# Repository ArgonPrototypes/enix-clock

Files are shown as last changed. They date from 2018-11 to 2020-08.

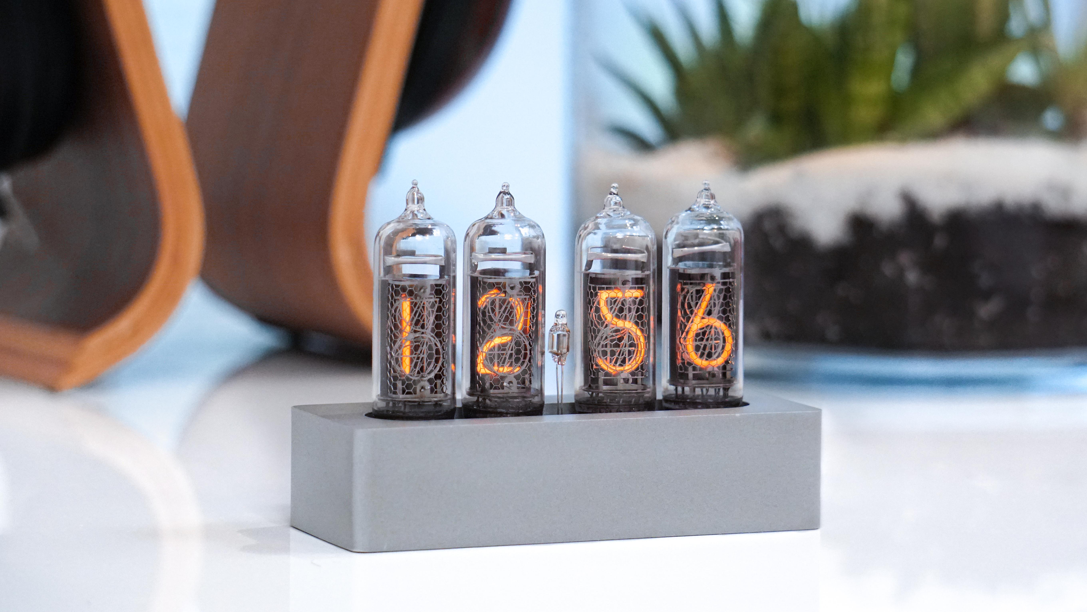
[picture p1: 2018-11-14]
MEDIA/Photos of the Enix/Kickstarter Promo Photo.jpg

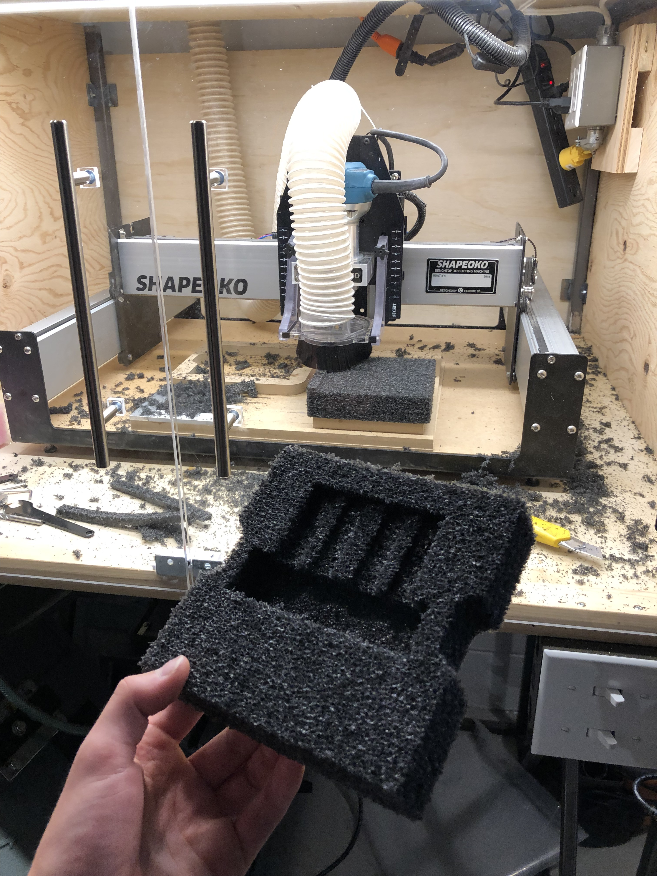
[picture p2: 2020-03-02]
PACKAGING/Top Foam/CNC Milled Foam.jpeg

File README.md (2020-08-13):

# Enix: The Modern Nixie Clock
### A beautifully sleek product that gives new life to vintage components
#### Learn more at our website: https://www.argonprototypes.com/
This repository contains hardware, software, CAD files, and much more!



# More info about each section:
## Electronic Hardware:
The circuit board was designed in EAGLE CAD V9.2.2. Most dimensions are in mm on this board. The Gerber files are in RS-274X and Excellon drill format. There are several external libraries used; Sparkfun, Adafruit, MacroFab, and a couple more for unique parts. There should not be any problems with opening the design files without the libraries installed.

Bottom Board
Top Board
## Software:
The majority of the software is written in VS Code with the PlatformIO extension, however the Arduino IDE works just as well. The microcontroller used is the ATMega32u4, which has an 8 bit architecture with a 16MHz clock speed, is 5V tolerant, and includes built in USB programmability. This microcontroller is found on the Arduino Micro, which can be selected from the IDE to be able to upload to the board.<br/> The libraries used are Arduino.h, TimerOne.h, RTClib.h, Adafruit_NeoPixel.h, Adafruit MCP9808.h, Wire.h, and EEPROM.h.

## Case
The outer case is a CNC milled block of Aluminum or Wood. The Aluminum cases are Vapour Blasted to give a satin look, and then Anodized in Black or Clear to add a protective coating. The Wood cases are sanded to a smooth finish, prior to coating in polyurethane or oil. <br/> To hold the electronics in the case, there is a 3D printed bottom plate which uses heat set inserts to bolt to the circuit board.

## Packaging
To safely ship the Enix, a custom cardboard box with the internal dimensions of 6x6x3" was designed and ordered through Packlane. 2 Foam CNC milled inserts tightly pack the clock and all included accessories, which includes the Enix, some stickers, a drink coaster, instruction manual, and a Mini-USB cable.<br/>
The Packlane box is shipped in a larger 8x8x5" standard cardboard box filled with packing peanuts to give added protection in shipping.

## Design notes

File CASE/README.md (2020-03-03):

# Files for the Case and Bottom Plate
##Case
##Bottom Plate
The bottom plate uses 4 M3 x 5mm Length x 3mm Outer Diameter brass heat set inserts and 4 button head Philips M3 x 6mm long bolts to fasten the bottom circuit board.<br/> The rectangular cutout on the bottom is to access the removable CR2032 battery which maintains timekeeping while the clock is unplugged. The case is connected to plate using 2 M3 countersunk Philips bolts made by Hammond Manufacturing - part number 1599HMS100BK for black and 1599HMS100 for silver.

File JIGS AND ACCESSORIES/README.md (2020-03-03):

# Jigs and Accessories
## Includes:
* 3D printed parts for bootloading the boards
* Pin header caps to prevent shorting the case and top PCB pins
* CNC fixtures for milling the foam packaging
* Nixie tube jig for evenly soldering in each tube

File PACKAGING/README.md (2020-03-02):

# Enix Clock Packaging
### The box the Enix ships in has an internal dimension of 6x6x3". To hold the clock and accessories, 1.5" laminated black polyethylene is CNC milled.
#CNC Milling Information
The foam inserts were machined using a Shapeoko 3 with a 6mm end mill made by Datron. The Datron product code is 00680560. A straight cut 6mm 2-flute from eBay was initially tested but with significantly worse results!
The Shapeoko's acceleration and maximum feedrates were increased through the MDI to speed up the cycle time as well.

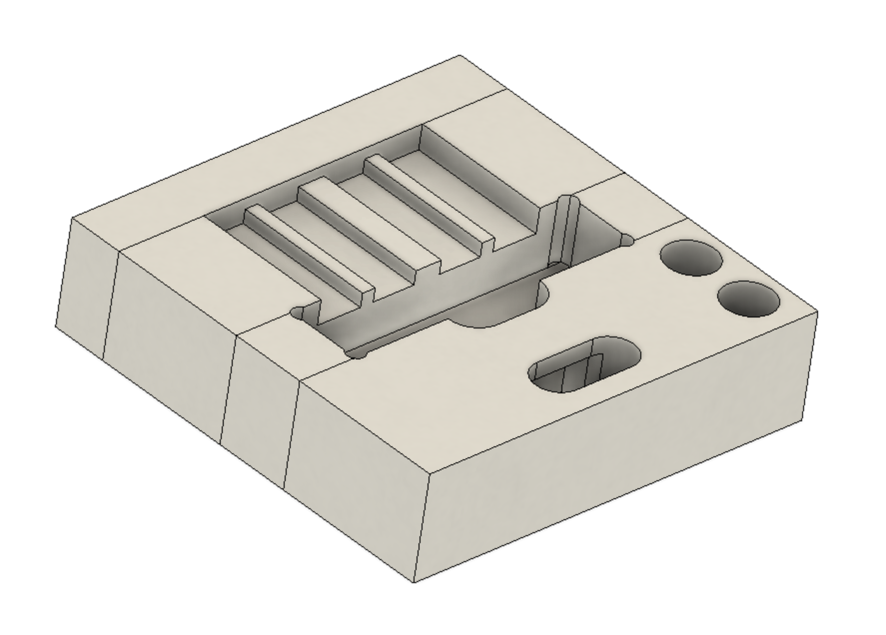
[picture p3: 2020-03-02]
PACKAGING/Bottom Foam/Rendered Photo Packaging Clock Side.png

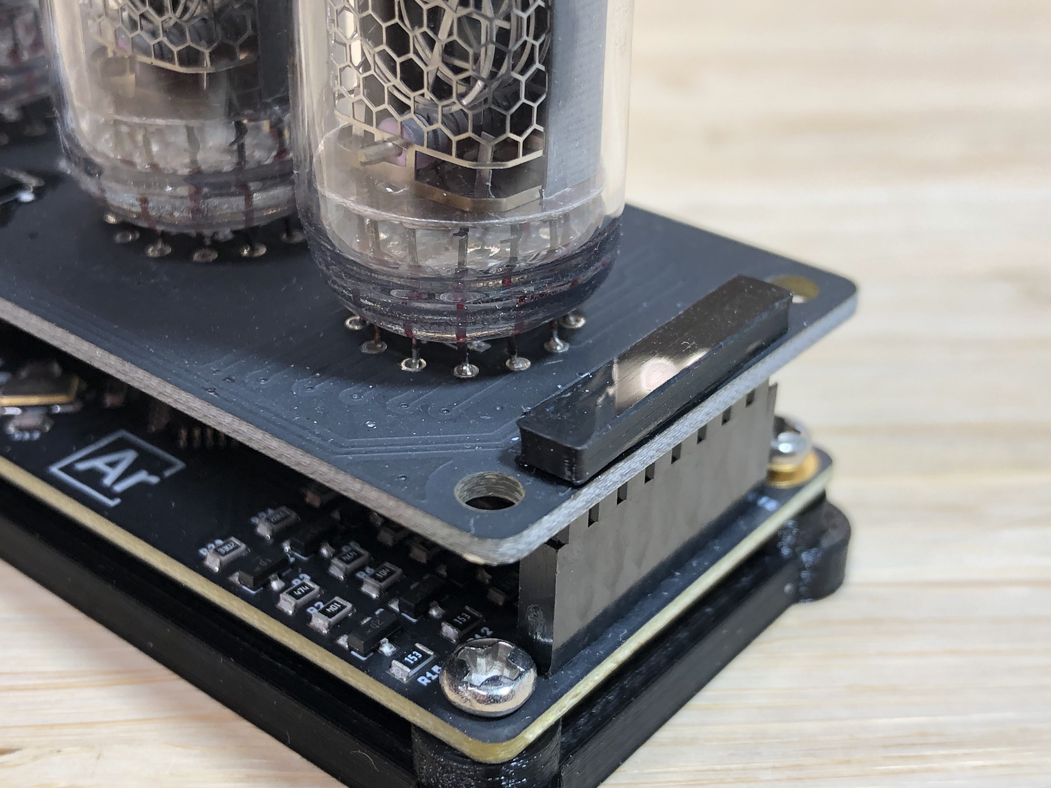
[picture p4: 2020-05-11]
JIGS AND ACCESSORIES/Pin Header Caps/1x8 Epoxied to Clock.jpeg

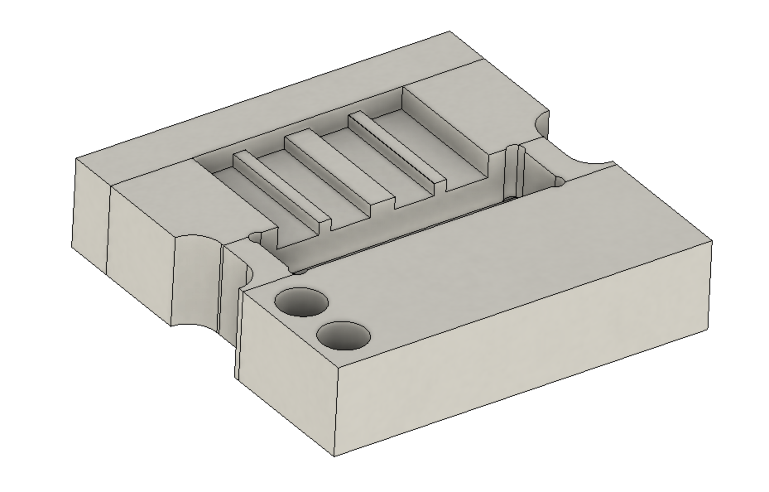
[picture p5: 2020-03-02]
PACKAGING/Top Foam/Rendered Packaging.png

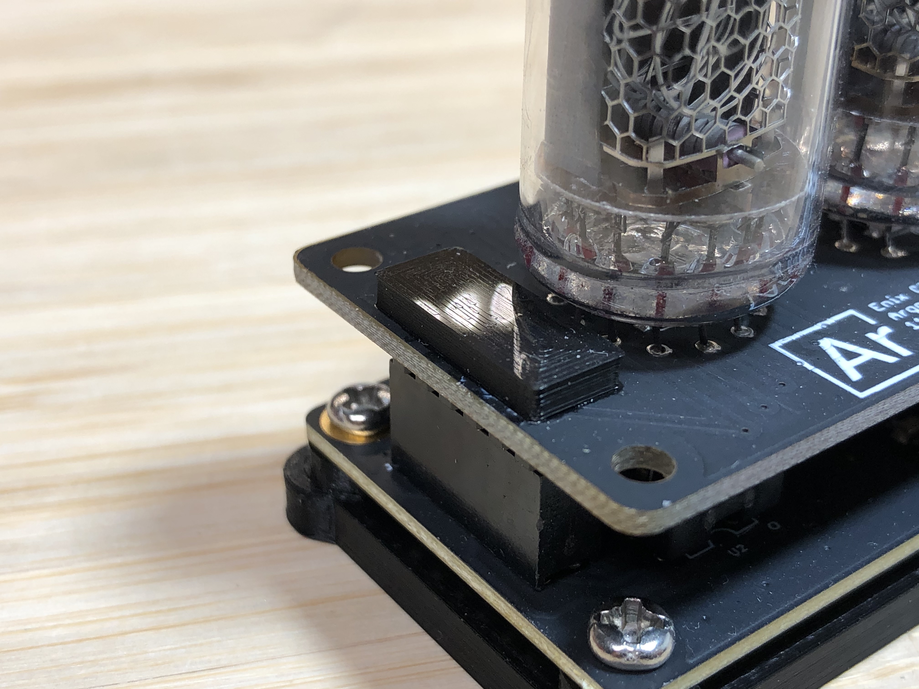
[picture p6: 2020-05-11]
JIGS AND ACCESSORIES/Pin Header Caps/2x6 Epoxied to Clock.jpeg

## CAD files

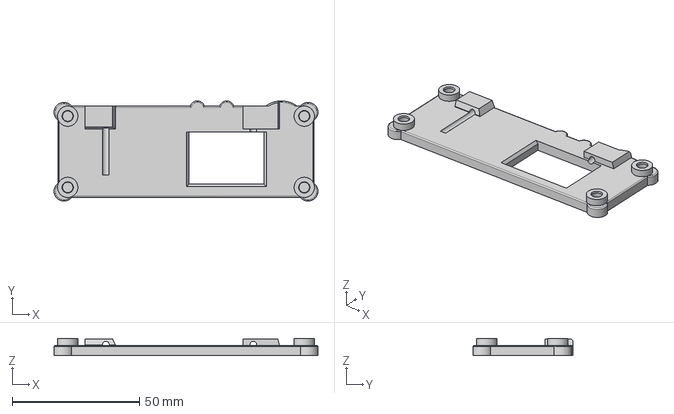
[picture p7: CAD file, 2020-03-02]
CASE/Bottom Plate - 3D printed/BottomPlate.step
103.8 x 39.4 x 6.75 mm

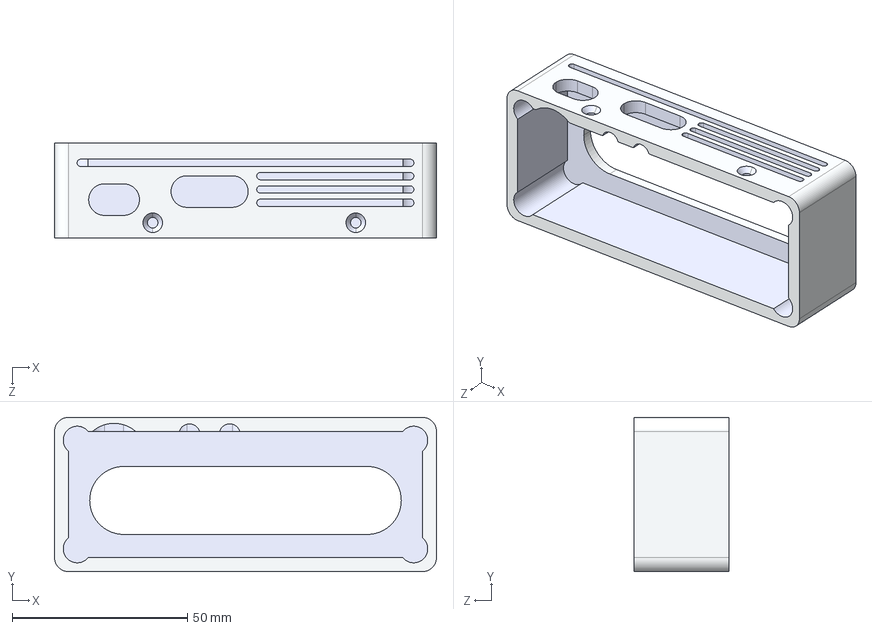
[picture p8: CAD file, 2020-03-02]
CASE/Top Case - CNC Milled/EnixCase.STEP
109.0 x 44.0 x 27.0 mm

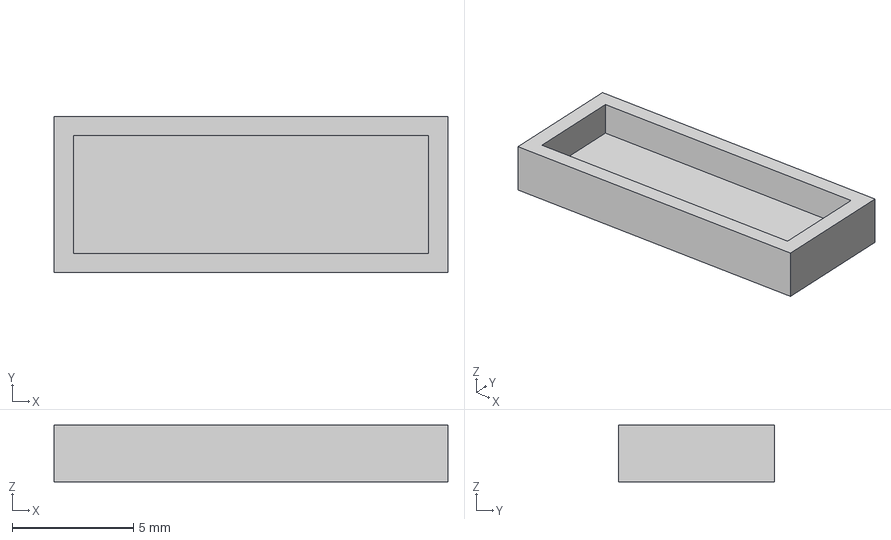
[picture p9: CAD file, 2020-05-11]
JIGS AND ACCESSORIES/Pin Header Caps/PinheaderCap2x6.step
16.2 x 6.45 x 2.35 mm

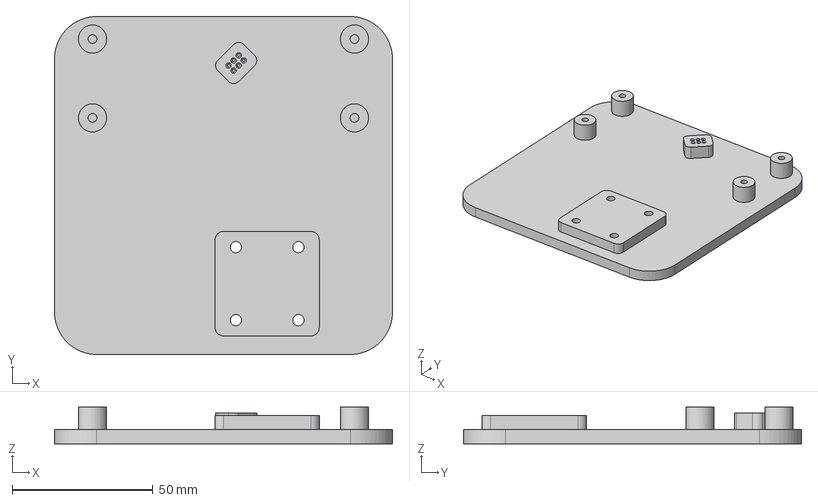
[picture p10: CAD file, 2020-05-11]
JIGS AND ACCESSORIES/Programming Jig/ProgrammingJig.step
120.0 x 120.0 x 13.0 mm

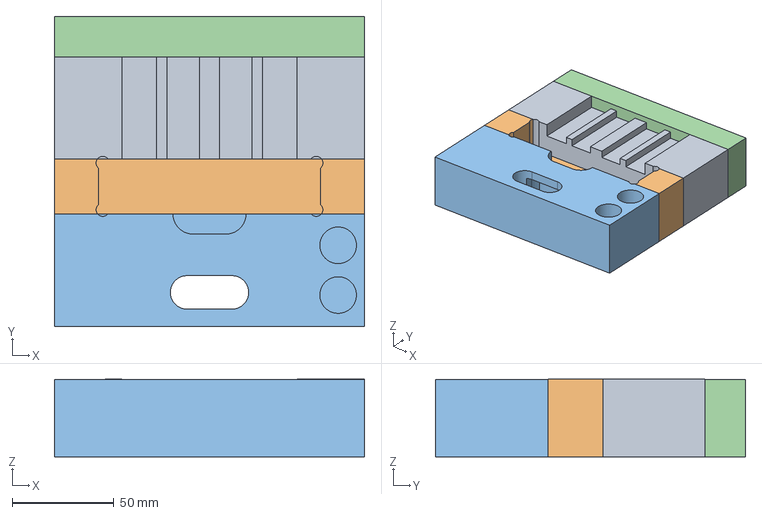
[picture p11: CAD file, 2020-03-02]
PACKAGING/Bottom Foam/Bottom Half Foam Packaging.step
152.5 x 152.4 x 38.1 mm

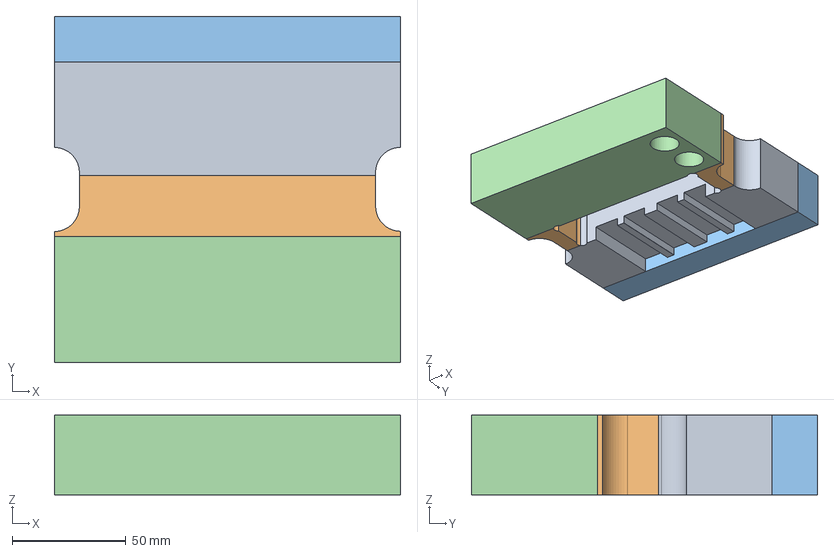
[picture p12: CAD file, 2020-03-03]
PACKAGING/Top Foam/Top Half Foam Packaging.step
152.5 x 152.4 x 35.1 mm

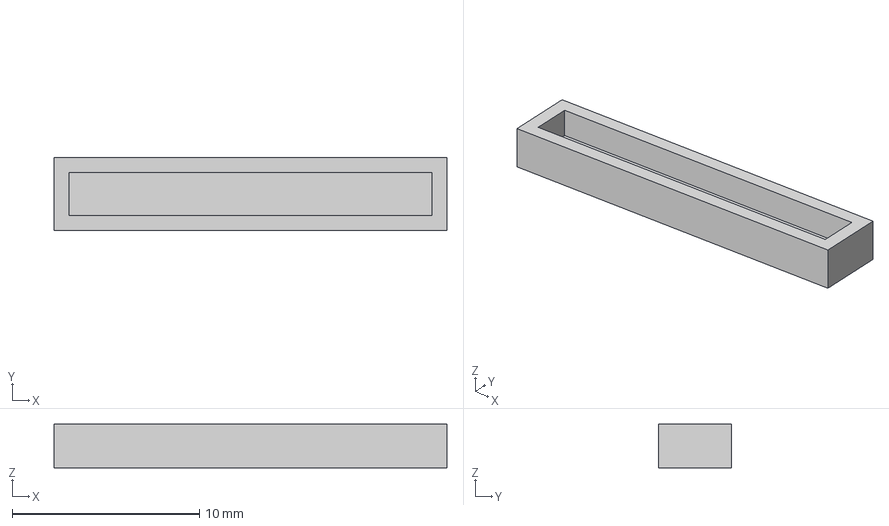
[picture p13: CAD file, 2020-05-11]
JIGS AND ACCESSORIES/Pin Header Caps/PinheaderCap1x8.step
21.0 x 3.90 x 2.35 mm

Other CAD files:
CASE/Bottom Plate - 3D printed/BottomPlate.stl
CASE/Top Case - CNC Milled/EnixCase.stl
JIGS AND ACCESSORIES/Pin Header Caps/PinheaderCap1x8.stl
JIGS AND ACCESSORIES/Pin Header Caps/PinheaderCap2x6.stl
JIGS AND ACCESSORIES/Programming Jig/ProgrammingJig.stl

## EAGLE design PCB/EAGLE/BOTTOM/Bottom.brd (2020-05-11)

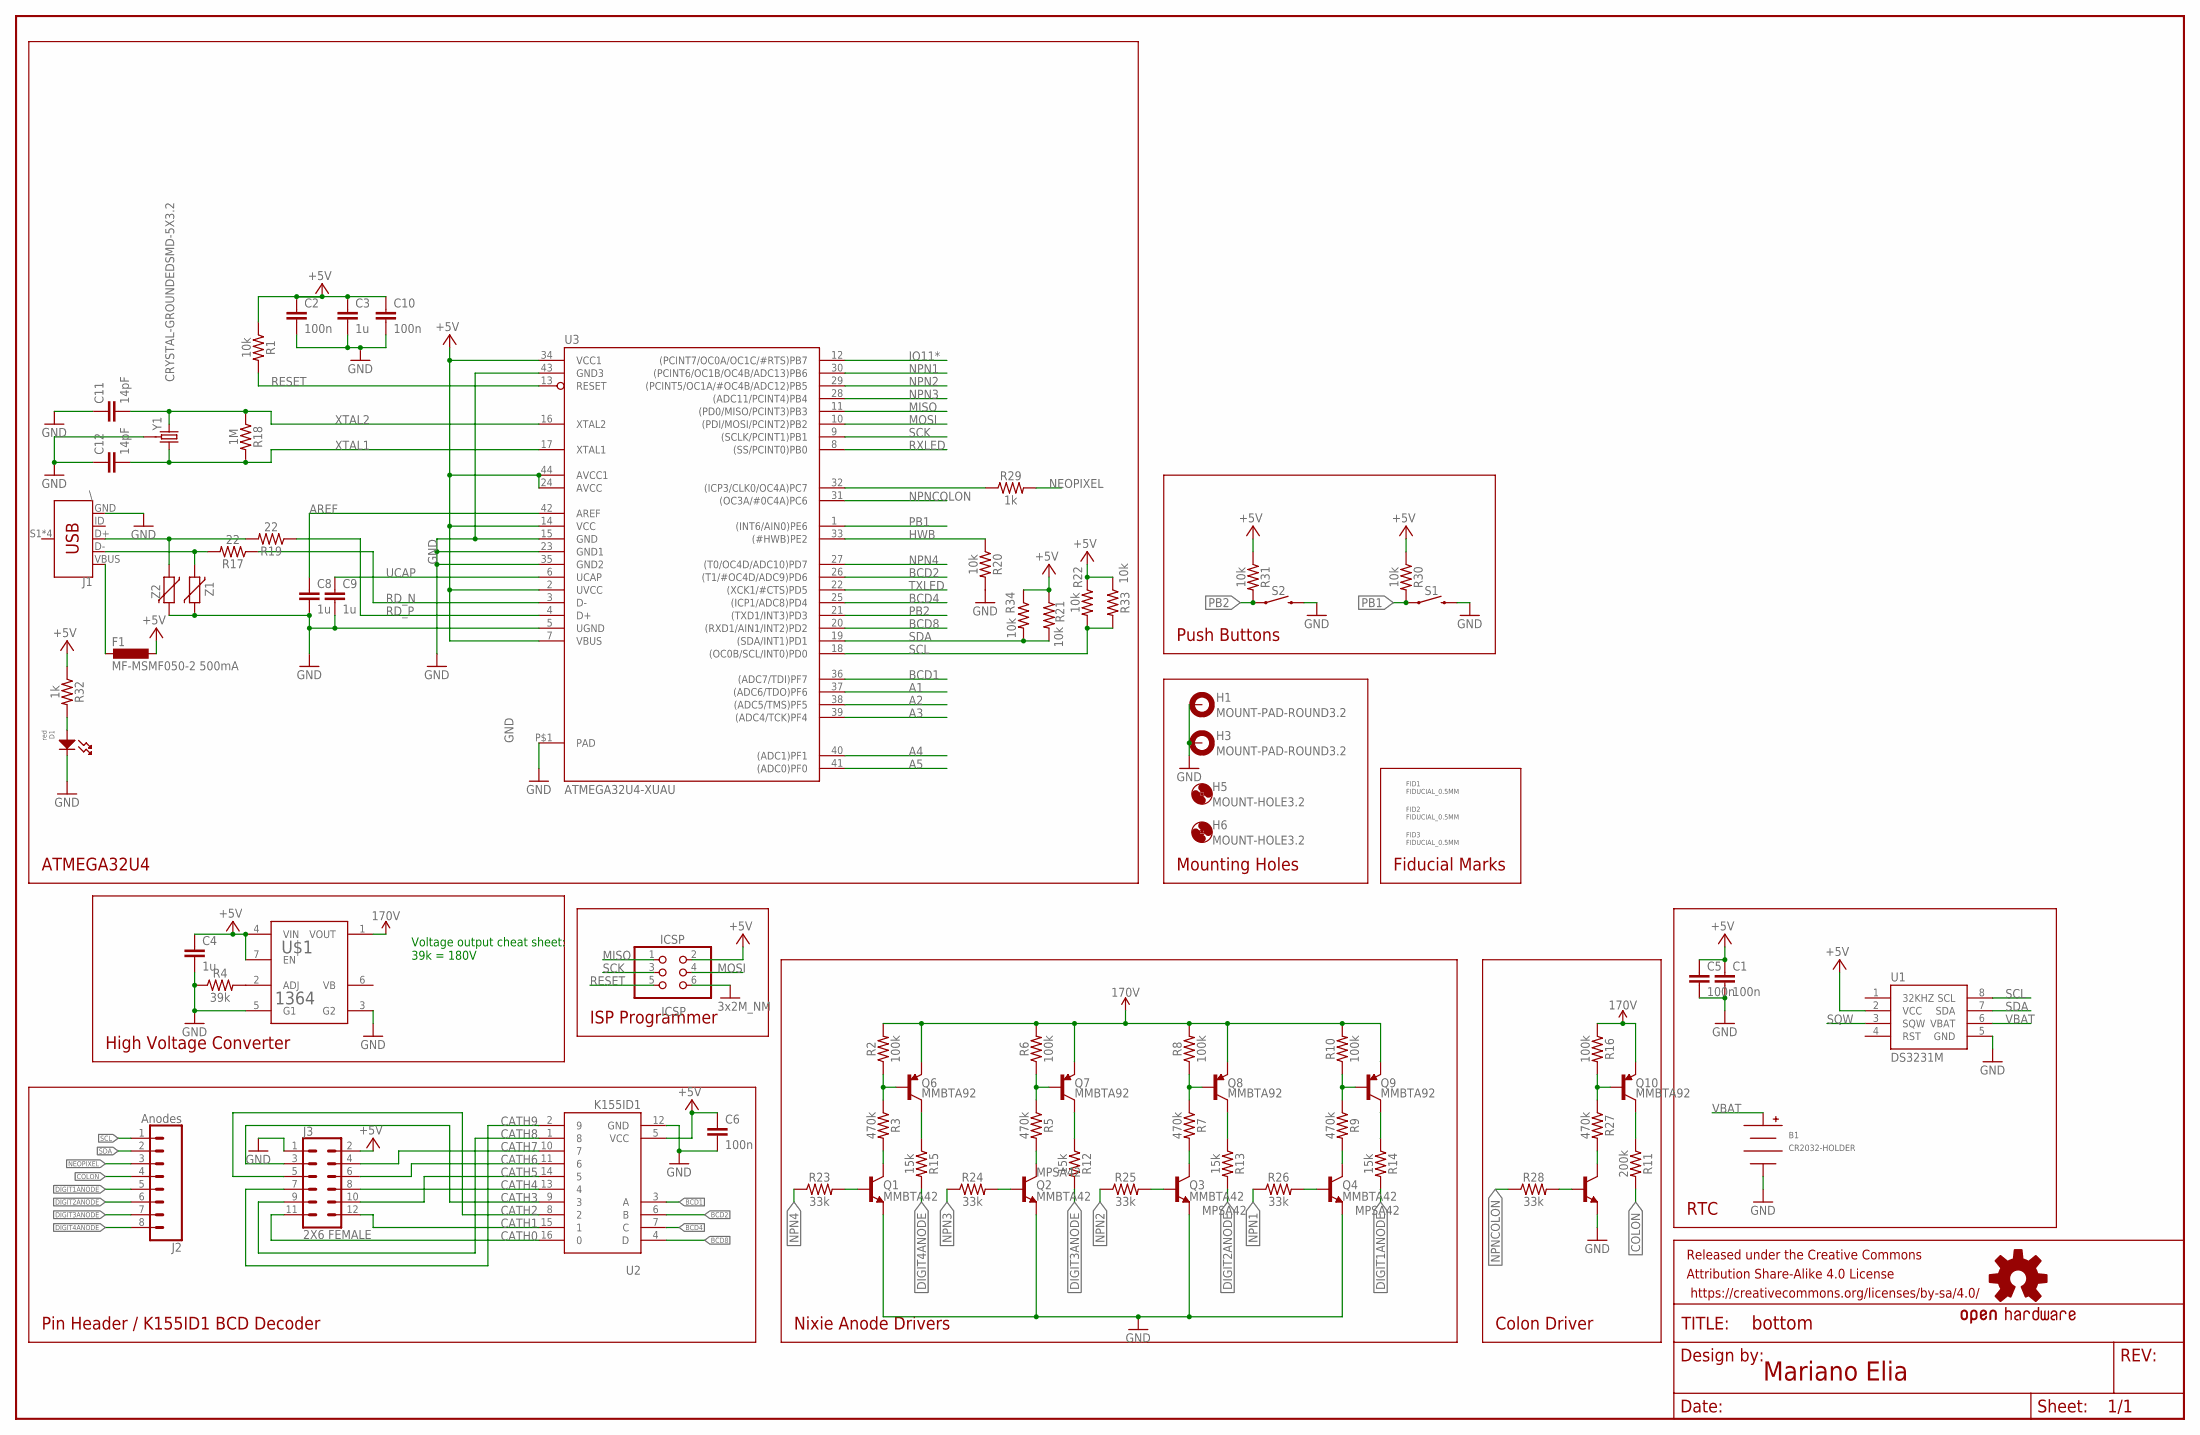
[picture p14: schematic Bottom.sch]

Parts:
B1: CR2032-HOLDER; CH28-2032LF
C1, C2, C5, C6, C10: 100n; 0805
C3, C4, C8, C9: 1u; 0805
C11, C12: 14pF; 0805
D1: red; LED0805
F1: MF-MSMF050-2 500mA; L1812
FID1, FID2, FID3: FIDUCIAL_0.5MM
FRAME1: FRAME-LEDGER; CREATIVE_COMMONS
H1, H3: MOUNT-PAD-ROUND3.2; 3,2-PAD
H5, H6: MOUNT-HOLE3.2; 3,2
ICSP: ICSP; 2X03
J1: \; USB-MINIB
J2: Anodes; 1X08_NO_SILK
J3: 2X6 FEMALE; 2X6_NOSILK
LOGO1: OSHW-LOGOL; OSHW-LOGO-L
Q1, Q2, Q3, Q4, Q5: MMBTA42; SOT23-3
Q6, Q7, Q8, Q9, Q10: MMBTA92; SOT23-3
R1, R20, R21, R22, R30, R31, R33, R34: 10k; 0805
R2, R6, R8, R10, R16: 100k; 0805
R3, R5, R7, R9, R27: 470k; 0805
R4: 39k; 0805
R11: 200k; 0805
R12, R13, R14, R15: 15k; 0805
R17, R19: 22; 0805
R18: 1M; 0805
R23, R24, R25, R26, R28: 33k; 0805
R29, R32: 1k; 0805
S1, S2: MOMENTARY-SWITCH-SPST-PTH-RIGHT-ANGLE-KIT; TACTILE_SWITCH_PTH_RIGHT_ANGLE_KIT
U1: DS3231M; SO08
U2: K155ID1; DIL16-KIT
U3: ATMEGA32U4-XUAU; TQFP44-PAD
U$1: 1364
Y1: CRYSTAL-GROUNDEDSMD-5X3.2; CRYSTAL-SMD-5X3.2-4PAD
Z1, Z2: VARISTORCN0603; CT/CN0603

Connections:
170V: Q6.2 (E), Q7.2 (E), Q8.2 (E), Q9.2 (E), Q10.2 (E), R2.2, R6.2, R8.2, R10.2, R16.1, U$1.1 (VOUT)
+5V: C1.1, C2.1, C3.1, C4.1, C5.1, C6.1, C10.1, F1.1, ICSP.2, J3.2, R1.1, R21.1, R22.1, R30.1, R31.1, R32.1, R33.1, R34.1, U1.2 (VCC), U2.5 (VCC), U3.2 (UVCC), U3.7 (VBUS), U3.14 (VCC), U3.24 (AVCC), U3.34 (VCC1), U3.44 (AVCC1), U$1.4 (VIN), U$1.7 (EN)
A1: U3.37 ((ADC6/TDO)PF6)
A2: U3.38 ((ADC5/TMS)PF5)
A3: U3.39 ((ADC4/TCK)PF4)
A4: U3.40 ((ADC1)PF1)
A5: U3.41 ((ADC0)PF0)
AREF: C8.1, U3.42 (AREF)
BCD1: U2.3 (A), U3.36 ((ADC7/TDI)PF7)
BCD2: U2.6 (B), U3.26 ((T1/#OC4D/ADC9)PD6)
BCD4: U2.7 (C), U3.25 ((ICP1/ADC8)PD4)
BCD8: U2.4 (D), U3.20 ((RXD1/AIN1/INT2)PD2)
CATH0: J3.11, U2.16 (0)
CATH1: J3.12, U2.15 (1)
CATH2: J3.5, U2.8 (2)
CATH3: J3.3, U2.9 (3)
CATH4: J3.8, U2.13 (4)
CATH5: J3.10, U2.14 (5)
CATH6: J3.6, U2.11 (6)
CATH7: J3.4, U2.10 (7)
CATH8: J3.9, U2.1 (8)
CATH9: J3.7, U2.2 (9)
COLON: J2.4, R11.2
DIGIT1ANODE: J2.5, R14.2
DIGIT2ANODE: J2.6, R13.2
DIGIT3ANODE: J2.7, R12.2
DIGIT4ANODE: J2.8, R15.2
D_N: J1.D-, R17.2, Z1.1
D_P: J1.D+, R19.2, Z2.1
GND: B1.NEG, C1.2, C2.2, C3.2, C4.2, C5.2, C6.2, C8.2, C9.2, C10.2, C11.1, C12.1, D1.CATHODE, H1.B3,2, H3.B3,2, ICSP.6, J1.GND, J3.1, Q1.2 (E), Q2.2 (E), Q3.2 (E), Q4.2 (E), Q5.2 (E), R4.1, R20.2, S1.2, S2.2, U1.5 (GND), U2.12 (GND), U3.5 (UGND), U3.15 (GND), U3.23 (GND1), U3.35 (GND2), U3.43 (GND3), U3.P$1 (PAD), U$1.3 (G2), U$1.5 (G1), Y1.2 (3), Y1.4 (3), Z1.2, Z2.2
HWB: R20.1, U3.33 ((#HWB)PE2)
IO11*: U3.12 ((PCINT7/OC0A/OC1C/#RTS)PB7)
MISO: ICSP.1, U3.11 ((PD0/MISO/PCINT3)PB3)
MOSI: ICSP.4, U3.10 ((PDI/MOSI/PCINT2)PB2)
unnamed: Q1.1 (B), R23.2
unnamed: Q2.1 (B), R24.2
unnamed: R4.2, U$1.2 (ADJ)
unnamed: Q3.1 (B), R25.2
unnamed: Q4.1 (B), R26.2
unnamed: Q6.1 (B), R2.1, R3.1
unnamed: Q1.3 (C), R3.2
unnamed: Q7.1 (B), R5.1, R6.1
unnamed: Q8.1 (B), R7.1, R8.1
unnamed: Q9.1 (B), R9.1, R10.1
unnamed: Q4.3 (C), R9.2
unnamed: Q2.3 (C), R5.2
unnamed: Q3.3 (C), R7.2
unnamed: Q5.1 (B), R28.2
unnamed: Q10.1 (B), R16.2, R27.1
unnamed: R29.1, U3.32 ((ICP3/CLK0/OC4A)PC7)
unnamed: Q5.3 (C), R27.2
unnamed: D1.ANODE, R32.2
unnamed: Q10.3 (C), R11.1
unnamed: Q7.3 (C), R12.1
unnamed: Q6.3 (C), R15.1
unnamed: Q8.3 (C), R13.1
unnamed: Q9.3 (C), R14.1
NEOPIXEL: J2.3, R29.2
NPN1: R26.1, U3.30 ((PCINT6/OC1B/OC4B/ADC13)PB6)
NPN2: R25.1, U3.29 ((PCINT5/OC1A/#OC4B/ADC12)PB5)
NPN3: R24.1, U3.28 ((ADC11/PCINT4)PB4)
NPN4: R23.1, U3.27 ((T0/OC4D/ADC10)PD7)
NPNCOLON: R28.1, U3.31 ((OC3A/#0C4A)PC6)
PB1: R30.2, S1.1, U3.1 ((INT6/AIN0)PE6)
PB2: R31.2, S2.1, U3.21 ((TXD1/INT3)PD3)
RD_N: R17.1, U3.3 (D-)
RD_P: R19.1, U3.4 (D+)
RESET: ICSP.5, R1.2, U3.13 (RESET)
RXLED: U3.8 ((SS/PCINT0)PB0)
SCK: ICSP.3, U3.9 ((SCLK/PCINT1)PB1)
SCL: J2.1, R22.2, R33.2, U1.8 (SCL), U3.18 ((OC0B/SCL/INT0)PD0)
SDA: J2.2, R21.2, R34.2, U1.7 (SDA), U3.19 ((SDA/INT1)PD1)
SQW: U1.3 (SQW)
TXLED: U3.22 ((XCK1/#CTS)PD5)
UCAP: C9.1, U3.6 (UCAP)
VBAT: B1.POS, U1.6 (VBAT)
VBUS: F1.2, J1.VBUS
XTAL1: C12.2, R18.2, U3.17 (XTAL1), Y1.1 (2)
XTAL2: C11.2, R18.1, U3.16 (XTAL2), Y1.3 (1)

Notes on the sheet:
ATMEGA32U4
High Voltage Converter
Pin Header / K155ID1 BCD Decoder
Nixie Anode Drivers
Colon Driver
RTC
Mariano Elia
Push Buttons
Mounting Holes
Fiducial Marks
ISP Programmer
Voltage output cheat sheet: 39k = 180V

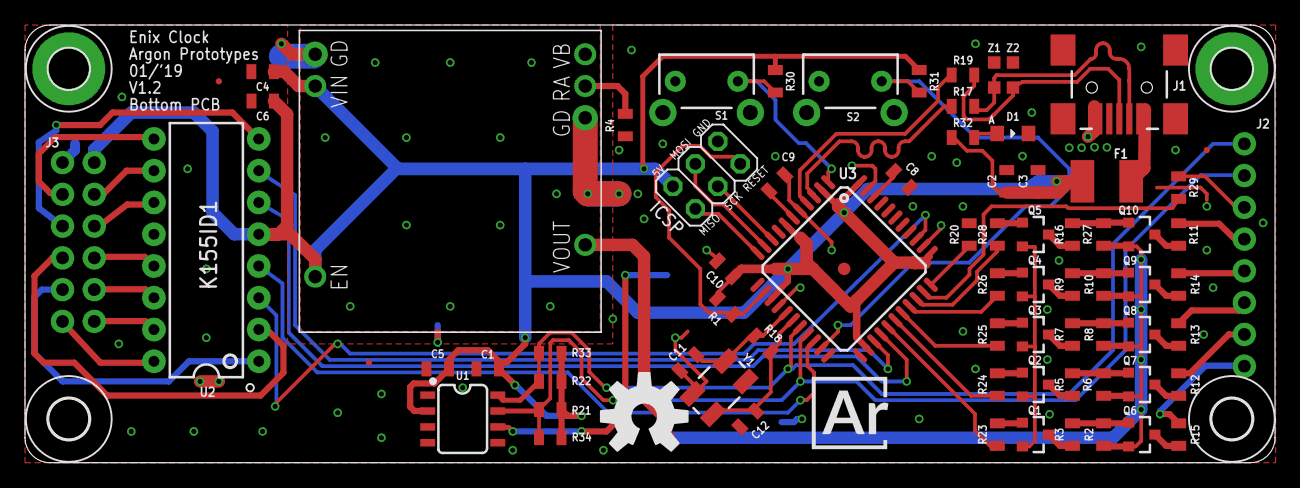
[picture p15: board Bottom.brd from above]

Board: 2 copper layers, 100.0 x 35.0 mm, 80 parts (1 on the bottom side), 70 nets.

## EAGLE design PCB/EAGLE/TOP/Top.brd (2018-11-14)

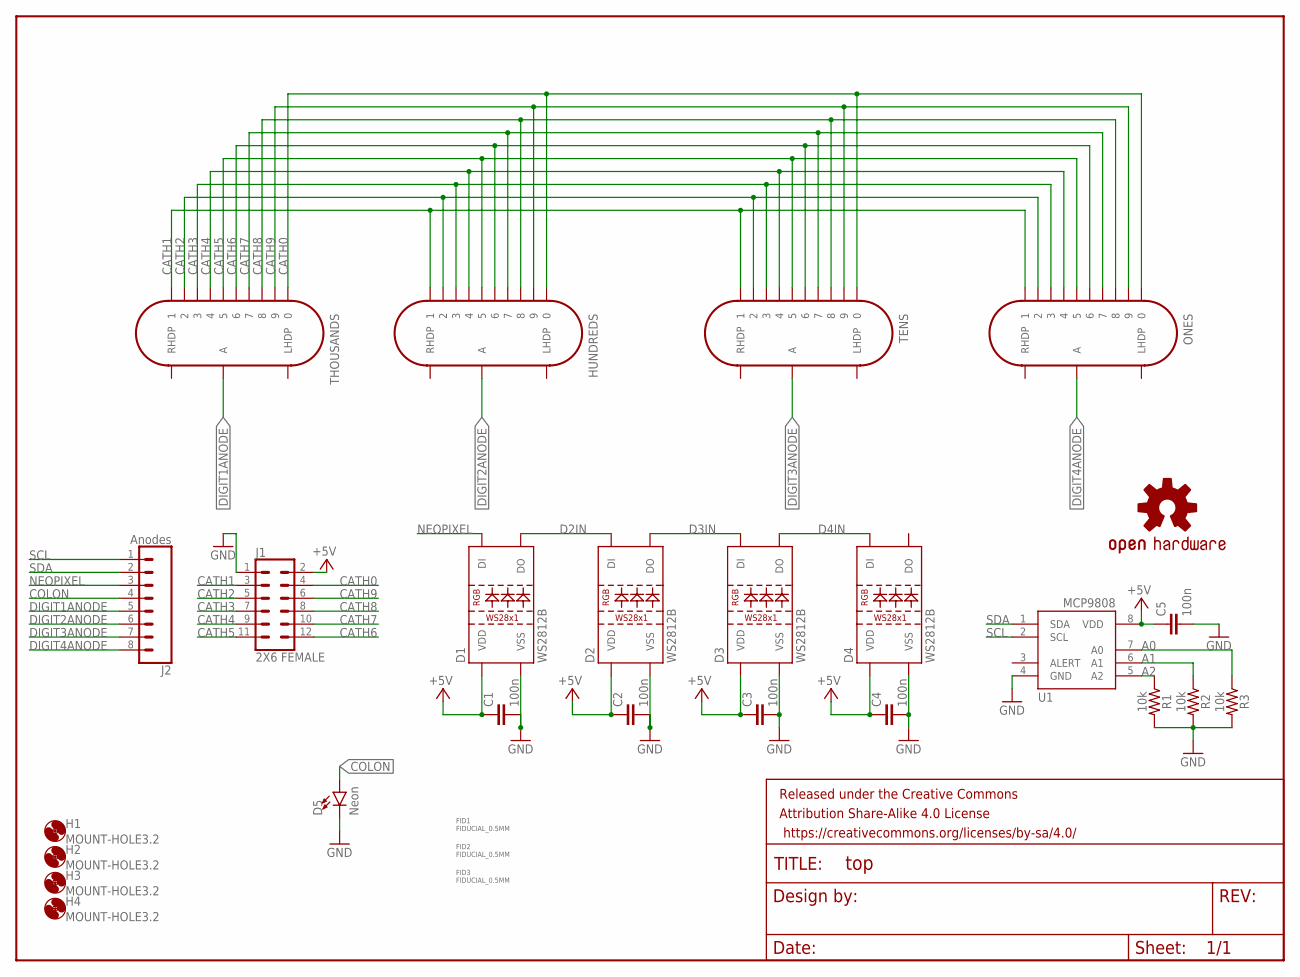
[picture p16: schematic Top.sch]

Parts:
C1, C2, C3, C4, C5: 100n; 0805
D1, D2, D3, D4: WS2812B
D5: Neon; LED_5MM
FID1, FID2, FID3: FIDUCIAL_0.5MM
FRAME1: FRAME-LETTER; CREATIVE_COMMONS
H1, H2, H3, H4: MOUNT-HOLE3.2; 3,2
HUNDREDS: IN-14
J1: 2X6 FEMALE; 2X6_NOSILK
J2: Anodes; 1X08_NO_SILK
LOGO1: OSHW-LOGOM; OSHW-LOGO-M
ONES: IN-14
R1, R2, R3: 10k; 0805
TENS: IN-14
THOUSANDS: IN-14
U1: MCP9808-E/MS; MSOP8_0.65MM

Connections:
+5V: C1.1, C2.1, C3.1, C4.1, C5.1, D1.1 (VDD), D2.1 (VDD), D3.1 (VDD), D4.1 (VDD), J1.2, U1.8 (VDD)
A0: R3.1, U1.7 (A0)
A1: R2.1, U1.6 (A1)
A2: R1.1, U1.5 (A2)
CATH0: HUNDREDS.1 (0), J1.4, ONES.1 (0), TENS.1 (0), THOUSANDS.1 (0)
CATH1: HUNDREDS.0 (1), J1.3, ONES.0 (1), TENS.0 (1), THOUSANDS.0 (1)
CATH2: HUNDREDS.9 (2), J1.5, ONES.9 (2), TENS.9 (2), THOUSANDS.9 (2)
CATH3: HUNDREDS.8 (3), J1.7, ONES.8 (3), TENS.8 (3), THOUSANDS.8 (3)
CATH4: HUNDREDS.7 (4), J1.9, ONES.7 (4), TENS.7 (4), THOUSANDS.7 (4)
CATH5: HUNDREDS.6 (5), J1.11, ONES.6 (5), TENS.6 (5), THOUSANDS.6 (5)
CATH6: HUNDREDS.5 (6), J1.12, ONES.5 (6), TENS.5 (6), THOUSANDS.5 (6)
CATH7: HUNDREDS.4 (7), J1.10, ONES.4 (7), TENS.4 (7), THOUSANDS.4 (7)
CATH8: HUNDREDS.3 (8), J1.8, ONES.3 (8), TENS.3 (8), THOUSANDS.3 (8)
CATH9: HUNDREDS.2 (9), J1.6, ONES.2 (9), TENS.2 (9), THOUSANDS.2 (9)
COLON: D5.A, J2.4
D2IN: D1.2 (DO), D2.4 (DI)
D3IN: D2.2 (DO), D3.4 (DI)
D4IN: D3.2 (DO), D4.4 (DI)
DIGIT1ANODE: J2.5, THOUSANDS.A
DIGIT2ANODE: HUNDREDS.A, J2.6
DIGIT3ANODE: J2.7, TENS.A
DIGIT4ANODE: J2.8, ONES.A
GND: C1.2, C2.2, C3.2, C4.2, C5.2, D1.3 (VSS), D2.3 (VSS), D3.3 (VSS), D4.3 (VSS), D5.K (C), J1.1, R1.2, R2.2, R3.2, U1.4 (GND)
NEOPIXEL: D1.4 (DI), J2.3
SCL: J2.1, U1.2 (SCL)
SDA: J2.2, U1.1 (SDA)

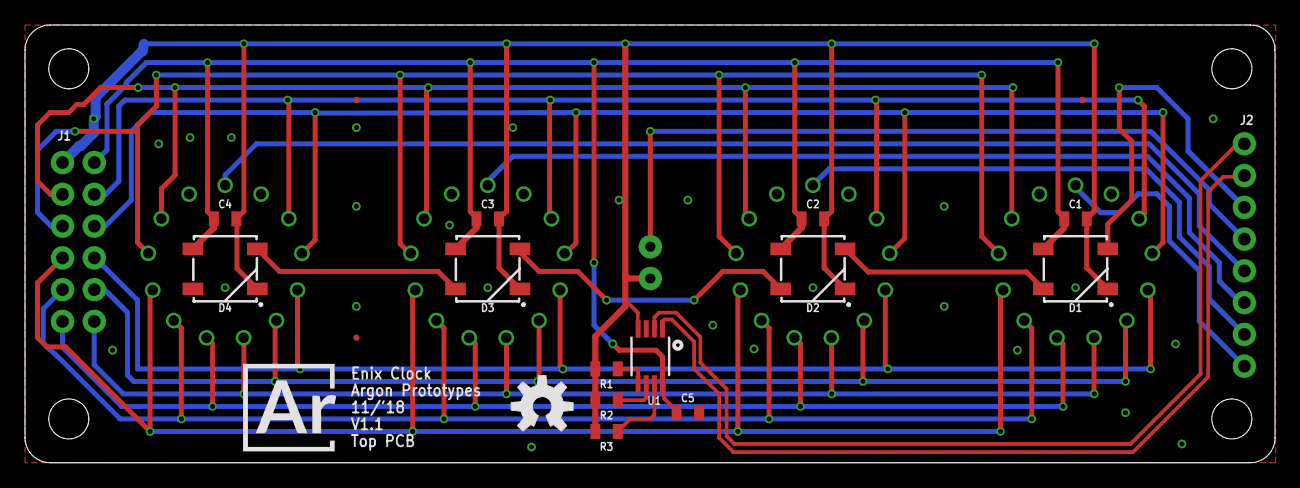
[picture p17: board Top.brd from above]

Board: 2 copper layers, 100.0 x 35.0 mm, 29 parts (0 on the bottom side), 26 nets.

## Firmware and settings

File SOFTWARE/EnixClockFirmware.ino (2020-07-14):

/*
   Project: Enix Clock Firmware
   More information about this project can be found at https://www.argonprototypes.com/
   and the GitHub page https://github.com/ArgonPrototypes/enix-clock
   
   In order to compile and upload the code to the Enix using the Arduino IDE, several steps must be done:

   1. Download and install the Arduino IDE. Once open select the Arduino Micro or Genuino Micro board.
      On a Mac and PC, this can be done by going to Tools -> Board -> Arduino Micro.

   2. Install all libraries below, the ones needing to be installed have been marked. 
      This can be done on a Mac and PC by going to Sketch -> Include Library -> Manage Libraries... and searching for each
      library and clicking on the install button.

   3. Compile the code by going to the menu bar and selecting Verify/Compile. If there are any errors, let us know and maybe there is some way we can help!

   4. Press upload. The clocks digits should turn off for a couple seconds as the new program is flashed. 
   Author: Argon Prototypes
   Contributor: Carson Cook
*/

#include "Arduino.h"
#include <TimerOne.h>          /* Needs to be installed. Choose one published by Jesse Tane*/
#include <RTClib.h>            /* Needs to be installed. Choose one published by Adafruit */
#include <Adafruit_NeoPixel.h> /* Needs to be installed. Called "Adafruit NeoPixel" in Arduino Library Manager */
#include <Adafruit_MCP9808.h>  /* Needs to be installed. Called "Adafruit MCP9808 Library" in Arduino Library Manager */
#include <Wire.h>
#include <EEPROM.h>

/*
  Format: (Hardware Pin Name - Software Name)

  //PORTB = 0b(PB7)(PB6-ANODE1)(PB5-ANODE2)(PB4-ANODE3)(PB3)(PB2)(PB1)(PB0)
  //PORTC = 0b(PC7-NEOPIXEL)(PC6-COLON)(NOT USED)(NOT USED)(NOT USED)(NOT USED)(NOT USED)(NOT USED)
  //PORTD = 0b(PD7-ANODE4)(PD6-BCD2)(PD5)(PD4-BCD4)(PD3-PUSHBUTTON2)(PD2-BCD8)(PD1)(PD0)
  //PORTE = 0b(NOT USED)(PE6-PUSHBUTTON1)(NOT USED)(NOT USED)(NOT USED)(PE2)(NOT USED)(NOT USED)
  //PORTF = 0b(PF7-BCD1)(PF6)(PF5)(PF4)(NOT USED)(NOT USED)(PF1)(PF0)
*/

#define ANODE1 10 // PB6
#define ANODE2 9  // PB5
#define ANODE3 8  // PB4
#define ANODE4 6  // PD7

#define BCD1 A0 // PF7
#define BCD2 12 // PD6
#define BCD4 4  // PD4
#define BCD8 0  // PD2

#define NEOPIXEL 13 // PC7
#define COLON 5     // PC6

// 2 Push Buttons
#define PUSHBUTTON1 7 // PE6 "Menu button"
#define PUSHBUTTON2 1 // PD3 "Increment button"

// EEPROM addresses
const uint8_t BITCHECK_ADDRESS = 0; //One-time run code
const uint8_t LEDMODE_ADDRESS = 1;
const uint8_t LEDBRIGHTNESSLEVEL_ADDRESS = 2;
const uint8_t IS12HOUR_ADDRESS = 3;
const uint8_t INCELSIUS_ADDRESS = 4;
const uint8_t MODESELECTOR_ADDRESS = 5;
const uint8_t ENABLEBLINKINGCOLON_ADDRESS = 6;
const uint8_t TEMPERATUREOFFSET_ADDRESS = 7;

volatile bool isButton1ClickState = false; //Can be set by 
unsigned long lastDebounceTime1 = 0;       //keeps track of time of last button 1 click

volatile bool isButton2ClickState = false;
unsigned long lastDebounceTime2 = 0; 

volatile uint8_t currentDigit = 0; //Will cycle from 0,1,2,3 and back around every millisecond
uint16_t currentBuffer = 0000;     //Starting buffer value.

bool enableBlinkingColon = true;            //True turns on the colon, false turns it off.
volatile uint8_t enableDigits = 0b00001111; //digit1,digit2,digit3,digit4
unsigned long previousModeMillis = 0;
uint16_t hundredMillisecondCounter = 0;

volatile int8_t temperatureOffset = 0; //Manual offset of up to +/- 7 degrees Celsius
volatile bool is12hour = true;         //24 or 12 hour clock. 24 is 0, 12 is 1
volatile bool inCelsius = true;        //Fahrenheit is 0, Celsius is 1
volatile uint8_t modeSelector = 0;     //

uint8_t ledBrightnesslevel = 3; //value from 1 to 5
const uint8_t ledBrightnessMap[5] = {51, 102, 153, 204, 255};
uint8_t ledSettingsArray[][4] = {
    // special function (Rainbow), red, green, blue
    {0, 0, 0, 0},       //OFF
    {1, 0, 0, 0},       //RAINBOW
    {0, 255, 255, 255}, //WHITE
    {0, 0, 0, 255},     //BLUE
    {0, 0, 102, 255},   //LIGHT BLUE
    {0, 0, 204, 102},   //TEAL
    {0, 0, 255, 51},    //SEAFOAM GREEN
    {0, 0, 255, 0},     //GREEN
    {0, 144, 3, 252},   //LAVENDER
    {0, 255, 0, 102},   //DARK PINK
    {0, 255, 0, 0},     //RED
    {0, 255, 51, 0},    //ORANGE
    {0, 255, 170, 0}    //YELLOW

};

const uint8_t numLEDModes = sizeof(ledSettingsArray) / sizeof(ledSettingsArray[0]);
uint8_t ledModeSelect = 0;

uint8_t currentMode = 0; //Global value which holds which mode the clock is in. IE time, date, or temp
Adafruit_MCP9808 tempsensor = Adafruit_MCP9808();
Adafruit_NeoPixel neopixels = Adafruit_NeoPixel(4, NEOPIXEL, NEO_GRB + NEO_KHZ800);
unsigned long rainbowNeoPixelsPreviousMillis = 0;
uint16_t curr8BitColor = 0;

const bool setTime = 0; //Set time using computers clock upon upload. Must be set to zero and uploaded again to continue normal operation
RTC_DS3231 rtc;

void setup()
{
  setupIO();
  setupTempSensor(); //Initialize the I2C MCP9808 temperature sensor and check everything is working
  setupRTC();        //Initialize the I2C DS3231M Real Time Clock and check everything is working
  setupTimer();
  //setupSerialPort(115200);  //Uncomment to access serial port
  setupNeoPixels();
  setupPushButtonInterrupts();

  //eraseAllEEPROM();  //Set every EEPROM cell to 0
  //setupEEPROMDefaults(); //Uncomment to set default variables

  retrieveEEPROM();
  currentBuffer = getTime(); //Load the current display buffer with the time.
}

void loop()
{
  modeHandler();
}

void setupIO()
{
  //Setup inputs and outputs. Same as pinMode(PIN, OUTPUT/INPUT);
  //A set bit (1) in a register indicates that the pin is an output.
  //Clearing a bit (0) sets the pin as an input
  DDRB |= 0b01110000; //Set outputs ANODE1, ANODE2, ANODE3 //pinMode(ANODE1, OUTPUT); pinMode(ANODE2, OUTPUT); pinMode(ANODE3, OUTPUT);
  DDRC |= 0b11000000; //Set outputs NEOPIXEL, COLON // pinMode(COLON, OUTPUT);
  DDRD |= 0b11010100; //Set outputs ANODE4, BCD2, BCD4, BCD8 // pinMode(ANODE4, OUTPUT);  pinMode(BCD2, OUTPUT); pinMode(BCD4, OUTPUT); pinMode(BCD8, OUTPUT);
  DDRD &= 0b11110111; //Clear input PUSHBUTTON2 // pinMode(PUSHBUTTON2, INPUT);
  DDRE &= 0b10111111; //Clear input PUSHBUTTON1 // pinMode(PUSHBUTTON1, INPUT);
  DDRF |= 0b10000000; //Set output BCD1 // pinMode(BCD1, OUTPUT);
}

void setupTimer()
{
  /*
     Timer1 on the ATMega32U4 is a hardware timer that can be set up to trigger an event at a precise time
     repeatedly. In this case, the multiplexing of the nixie tubes is automatically triggered regardless
     of delays in main loops. 
  */
  Timer1.initialize(1000);                   // set a timer of length 1000 microseconds / 1 millisecond
  Timer1.attachInterrupt(nixieMultiplexISR); //Every millisecond run the Interrupt Service Routine. This will display the next digit on the display, from left to right.
}

void setupSerialPort(int baudrate)
{
  Serial.begin(baudrate);
}

void setupNeoPixels()
{
  neopixels.begin(); //Initialize the neopixels
  allNeoPixelsOff(); //Turn off all neopixels to start
}

void setupPushButtonInterrupts()
{
  attachInterrupt(digitalPinToInterrupt(PUSHBUTTON1), button1ISR, FALLING); //Interrupt triggered when button 1 is pushed
  attachInterrupt(digitalPinToInterrupt(PUSHBUTTON2), button2ISR, FALLING); //Interrupt triggered when button 2 is pushed
}

//Fetch the user settings
void retrieveEEPROM()
{
  ledModeSelect = EEPROM.read(LEDMODE_ADDRESS);
  //Check for bad ledModeSelect value
  if (ledModeSelect >= numLEDModes)
    ledModeSelect = 0;

  ledBrightnesslevel = EEPROM.read(LEDBRIGHTNESSLEVEL_ADDRESS);
  if (ledBrightnesslevel < 0 || ledBrightnesslevel > 5)
    ledBrightnesslevel = 3;

  is12hour = EEPROM.read(IS12HOUR_ADDRESS);
  //Check for bad is12hour
  if (is12hour != 1 && is12hour != 0)
    is12hour = 0;

  enableBlinkingColon = EEPROM.read(ENABLEBLINKINGCOLON_ADDRESS);
  if (enableBlinkingColon != 1 && enableBlinkingColon != 0)
    enableBlinkingColon = 1;

  inCelsius = EEPROM.read(INCELSIUS_ADDRESS);
  //Check for bad inCelsius value
  if (inCelsius != 1 && inCelsius != 0)
    inCelsius = 0;

  temperatureOffset = EEPROM.read(TEMPERATUREOFFSET_ADDRESS);
  if (temperatureOffset < -7 || temperatureOffset > 7)
    temperatureOffset = 0;

  modeSelector = EEPROM.read(MODESELECTOR_ADDRESS);
  if (modeSelector < 1 || modeSelector > 4)
    modeSelector = 1;
}

//Erase the entire EEPROM. Only used when setting up a new clock.
void eraseAllEEPROM()
{
  for (int i = 0; i < EEPROM.length(); i++)
  {
    EEPROM.update(i, 0);
  }
}

//Set up EEPROM for a new clock to the default setup.
void setupEEPROMDefaults()
{
  EEPROM.update(LEDMODE_ADDRESS, 0);
  EEPROM.update(LEDBRIGHTNESSLEVEL_ADDRESS, 3);
  EEPROM.update(IS12HOUR_ADDRESS, true);
  EEPROM.update(ENABLEBLINKINGCOLON_ADDRESS, true);
  EEPROM.update(INCELSIUS_ADDRESS, true);
  EEPROM.update(TEMPERATUREOFFSET_ADDRESS, 0);
  EEPROM.update(MODESELECTOR_ADDRESS, 2);
}

/*
   Controls the normal operation of the clock. Uses polling timers to select when modes are
   shown and for how long.
   The modes that are shown can be selected in the settings menu.
   Mode 1: Time, Date, Temperature
   Mode 2: Time, Date
   Mode 3: Time, Temperature
   Mode 4: Time

   With each mode, transitions are used which cycles every digit to both be visually pleasing, and prevent cathode poisoning on the digits. 
*/

void modeHandler()
{
  if (isButton1ClickState) //Enter the settings menu if button 1 is clicked
  {
    isButton1ClickState = false;
    settingsManager();
  }
  controlLEDs();
  unsigned long currentModeMillis = millis();
  if (currentModeMillis - previousModeMillis > 100)
  { //run every hundred milliseconds
    previousModeMillis = currentModeMillis;
    hundredMillisecondCounter++;
    switch (modeSelector)
    {
    case 1: // Time, Date, Temperature
      //Global variable currentMode is used to select which mode the clock is in
      switch (currentMode)
      {
      case 0:
        handleTimeMode();
        if (hundredMillisecondCounter % 500 == 0) // 50 seconds
        {
          turnOffColon();                //turn off the colon
          nixieTransition(3, getDate()); //Transition to Date
          currentMode = 1;
          hundredMillisecondCounter = 0;
        }
        break;
      case 1:
        handleDateMode();
        if (hundredMillisecondCounter % 40 == 0) // 4 seconds
        {
          hundredMillisecondCounter = 0;
          nixieTransition(4, getTemperature());
          currentMode = 2;
        }
        break;
      case 2:
        handleTemperatureMode();
        if (hundredMillisecondCounter % 40 == 0) // 4 seconds
        {
          enableDigits = 0b1111;
          hundredMillisecondCounter = 0;
          nixieTransition(1, 0);
          currentMode = 0;
        }
        break;

      default:
        currentMode = 0;
        break;
      }

      break;

    case 2: // Time, Date
      switch (currentMode)
      {
      case 0:
        handleTimeMode();
        if (hundredMillisecondCounter % 500 == 0) // 50 seconds
        {
          turnOffColon();                //turn off the colon
          nixieTransition(3, getDate()); //Transition to Date
          currentMode = 1;
          hundredMillisecondCounter = 0;
        }
        break;
      case 1:
        handleDateMode();
        if (hundredMillisecondCounter % 40 == 0) // 4 seconds
        {
          hundredMillisecondCounter = 0;
          nixieTransition(1, 0);
          currentMode = 0;
        }
        break;
      }
      break;
    case 3: // Time, Temperature
      switch (currentMode)
      {
      case 0:
        handleTimeMode();
        if (hundredMillisecondCounter % 500 == 0) // 50 seconds
        {
          turnOffColon();                       //turn off the colon
          nixieTransition(4, getTemperature()); //Transition to Date
          currentMode = 2;
          hundredMillisecondCounter = 0;
        }
        break;

      case 2:
        handleTemperatureMode();
        if (hundredMillisecondCounter % 40 == 0) // 4 seconds
        {
          enableDigits = 0b1111;
          hundredMillisecondCounter = 0;
          nixieTransition(1, 0);
          currentMode = 0;
        }
        break;
      }
      break;
    case 4: // Time
      handleTimeMode();
      if (hundredMillisecondCounter % 500 == 0) // 50 seconds
      {
        enableDigits = 0b1111;
        hundredMillisecondCounter = 0;
        nixieTransition(1, 0);
      }
      break;
      break;
    }
  }
}

void handleTimeMode()
{
  //Only retrieve time when colon is disabled.
  if ((0b01000000 && PORTC) == 0)
  {
    currentBuffer = getTime(); //retrieve the current time
  }

  if (enableBlinkingColon && (hundredMillisecondCounter % 5 == 0))
  { //Toggle every half second
    toggleColon();
  }
}

void handleDateMode()
{
  currentBuffer = getDate();
}

void handleTemperatureMode()
{
  enableDigits = 0b0011;
  if (hundredMillisecondCounter < 2)
  { //only fetch temperature once
    currentBuffer = getTemperature();
  }
}

/*

*/
void controlLEDs()
{
  neoPixelsSetBrightness(ledBrightnesslevel);
  if (ledSettingsArray[ledModeSelect][0] == 0)
  { //not a special mode like rainbow
    for (int i = 0; i < 4; i++)
    {
      //Fetch the RGB color settings from ledSettingsArray[][]
      neopixels.setPixelColor(i, ledSettingsArray[ledModeSelect][1], ledSettingsArray[ledModeSelect][2], ledSettingsArray[ledModeSelect][3]);
    }
    neopixels.show();
  }
  else if (ledSettingsArray[ledModeSelect][0] == 1)
  {
    rainbow();
    neopixels.show();
  }
}

/*
   Manages the settings menu system.

   The settings in order are:
   1. Year    : 2019 to 2030. The purpose of the year is to decide whether it is a leap year or not
                February has 29 days instead of the usual 28. Displayed on all 4 digits with teal under lighting
   2. Month   : 1 to 12. Displayed on the left 2 digits only with green under lighting.
   3. Day     : 1 to (28,29,30,31) depending on if it is a leap year, and the current month. Displayed on the right 2 digits only with green under lighting.
   4. Hour    : 0 to 23. (0 being midnight, 23 being 11 pm.) Displayed on the left 2 digits only with blue under lighting.
   5. Minute  : 0 to 59. Displayed on the right 2 digits only with blue under lighting.

   ---- At this point the RTC is sent the new date and time and it is stored ----
   ---- Every setting after this is individually saved to EEPROM after choosing the setting ----

   6. 12/24 hour      : Either 12 or 24 is displayed on the right 2 digits with pink under lighting.
   7. Blinking Colon  : A lit neon bulb signifies blinking, unlit indicates no blinking. Teal under lighting.
   8. Under lighting  : All 4 L.E.D's light up to signify the chosen color. Order is none, rainbow, then several static colors.
   9. Under lighting brightness : 1 to 5. Displayed on the right 2 digits, with all under lighting on in the selected color, otherwise in pink to show brightness. 
   10. Temperature Units : Celsius or Fahrenheit. Displays the current temperature in either unit on the right 2 digits, with red under lighting.
   11. Temperature Offset : -7 to 7 in degrees Celsius (Each degree C is 1.8 degrees F). Displayed on the right 2 digits with pink under lighting. The center neon colon acts as a negative sign.
   12. Mode Select    : 1 to 4. Shown on the right 2 digits with blue underlighting.
                          Mode 1: Time, Date, Temperature
                          Mode 2: Time, Date
                          Mode 3: Time, Temperature
                          Mode 4: Time 
    ---- Exit the menu system ----
*/

void settingsManager()
{
  isButton2ClickState = false; //reset global flag
  bool copyOfis12hour = is12hour;
  bool copyOfBlinkingColon = enableBlinkingColon;
  uint8_t copyOfModeSelector = modeSelector;
  is12hour = false; //Make 24 hour clock for setting
  uint16_t currentDate = getDate();
  uint16_t currentTime = getTime();
  uint8_t currentMonth = currentDate / 100;
  uint8_t currentDay = currentDate % 100;
  uint8_t currentHour = currentTime / 100;
  uint8_t currentMinute = currentTime % 100;
  uint16_t currentYear = getYear();
  turnOffColon();
  currentBuffer = currentHour;
  allNeoPixelsOff();

  //Setting 1: Choose Year
  currentYear = chooseYear(currentYear);
  //Setting 2: Choose month
  currentMonth = chooseMonth(currentMonth);
  //Setting 3: Choose Day
  currentDay = chooseDay(currentDay, currentYear, currentMonth);
  //Setting 4: Choose hour
  currentHour = chooseHour(currentHour);
  //Setting 5: Choose minute
  currentMinute = chooseMinute(currentMinute);
  //Send the new time to the RTC
  rtc.adjust(DateTime(currentYear, currentMonth, currentDay, currentHour, currentMinute, 0));

  //Choose 24 or 12 time setting
  is12hour = chooseis12hour(copyOfis12hour);
  EEPROM.update(IS12HOUR_ADDRESS, is12hour);

  //Choose Blinking Colon
  enableBlinkingColon = chooseEnableBlinkingColon(copyOfBlinkingColon);
  EEPROM.update(ENABLEBLINKINGCOLON_ADDRESS, enableBlinkingColon);

  //Choose LED underlighting settings
  ledModeSelect = chooseLEDMode();
  EEPROM.update(LEDMODE_ADDRESS, ledModeSelect);

  //Choose LED brightness settings
  chooseLEDBrightness();
  EEPROM.update(LEDBRIGHTNESSLEVEL_ADDRESS, ledBrightnesslevel);

  //Choose Fahrenheit/Celsius setting
  inCelsius = chooseInCelsius();
  EEPROM.update(INCELSIUS_ADDRESS, inCelsius);

  temperatureOffset = chooseTemperatureOffset();
  EEPROM.update(TEMPERATUREOFFSET_ADDRESS, temperatureOffset);

  modeSelector = chooseModeSelector(modeSelector);
  EEPROM.update(MODESELECTOR_ADDRESS, modeSelector);

  //Restore
  isButton1ClickState = false;
  enableDigits = 0b1111;
  currentMode = 0;
  allNeoPixelsOff();
}

uint8_t chooseHour(uint8_t currentHour)
{
  isButton1ClickState = false;
  enableDigits = 0b1100;                 // turn off right 2 digits
  neopixels.setPixelColor(3, 0, 0, 255); //underlight left most LED
  neopixels.setPixelColor(2, 0, 0, 255); //underlight one over from the left most
  neopixels.show();

  while (!isButton1ClickState)
  {
    currentBuffer = currentHour * 100; // shift hour val to the left 2 digits
    if (isButton2ClickState)
    {                              // if button1
      isButton2ClickState = false; //reset button 2 counter
      if (currentHour == 23)
      {
        currentHour = 0; //rollover
      }
      else
      {
        currentHour++;
      }
    }
    Serial.print("Hour: ");
    Serial.println(currentHour);
    delay(100);
  }
  allNeoPixelsOff(); // turn off all pixels
  return currentHour;
}

uint8_t chooseMinute(uint8_t currentMinute)
{
  isButton1ClickState = false; //reset isButton1ClickState
  neopixels.setPixelColor(1, 0, 0, 255);
  neopixels.setPixelColor(0, 0, 0, 255);
  neopixels.show();
  enableDigits = 0b0011;
  while (!isButton1ClickState)
  {
    currentBuffer = currentMinute; //currentMinute;
    if (isButton2ClickState)
    {                              //button 2 incremented
      isButton2ClickState = false; //reset global flag
      if (currentMinute == 59)
      {
        currentMinute = 0;
      }
      else
      {
        currentMinute++;
      }
    }
    Serial.print("Minute: ");
    Serial.println(currentMinute);
    delay(100);
  }
  allNeoPixelsOff();
  return currentMinute;
}

uint16_t chooseYear(uint16_t currentYear)
{
  isButton1ClickState = false; //reset isButton1ClickState
  neopixels.setPixelColor(0, 0, 255, 128);
  neopixels.setPixelColor(1, 0, 255, 128);
  neopixels.setPixelColor(2, 0, 255, 128);
  neopixels.setPixelColor(3, 0, 255, 128);
  neopixels.show();

  if (currentYear < 2018 || currentYear > 2030)
    currentYear = 2018;
  currentBuffer = currentYear;
  enableDigits = 0b1111;
  while (!isButton1ClickState)
  {
    currentBuffer = currentYear;
    if (isButton2ClickState)
    { //button 2 incremented
      isButton2ClickState = false;
      if (currentYear >= 2030)
      {
        currentYear = 2018;
      }
      else
        currentYear++;
    }
    delay(100);
  }
  allNeoPixelsOff();
  return currentYear;
}

uint8_t chooseMonth(uint8_t currentMonth)
{
  isButton1ClickState = false; //reset isButton1ClickState
  enableDigits = 0b1100;
  neopixels.setPixelColor(2, 0, 255, 0);
  neopixels.setPixelColor(3, 0, 255, 0);
  neopixels.show();
  while (!isButton1ClickState)
  {
    currentBuffer = currentMonth * 100;
    if (isButton2ClickState)
    {                              //button 2 incremented
      isButton2ClickState = false; //reset global flag
      if (currentMonth == 12)
      {
        currentMonth = 1;
      }
      else
      {
        currentMonth++;
      }
    }
    delay(100);
  }
  allNeoPixelsOff();
  return currentMonth;
}

uint8_t chooseDay(uint8_t day, uint16_t year, uint8_t month)
{
  isButton1ClickState = false; //reset isButton1ClickState
  enableDigits = 0b1100;
  neopixels.setPixelColor(1, 0, 255, 0);
  neopixels.setPixelColor(0, 0, 255, 0);
  neopixels.show();
  enableDigits = 0b0011;
  if (day > daysInMonth(month, year))
  {
    day = 1;
  }
  while (!isButton1ClickState)
  {
    currentBuffer = day;
    if (isButton2ClickState)
    {                              //button 2 incremented
      isButton2ClickState = false; //reset global flag

      if (day >= daysInMonth(month, year))
      {
        day = 1; // rollover day in the month select
      }
      else
      {
        day++;
      }
    }
    delay(100);
  }
  allNeoPixelsOff();
  return day;
}
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

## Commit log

2018-11-14 Add gerber files, and eagle files
    [Bottom.brd, Bottom.sch, Top.brd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]
2018-11-14 Separate Gerber and Eagle into 2 separate folders
2020-03-03 Update README for packaging, jigs, and case
    [Top Half Foam Packaging.step]
2020-05-11 Update boards to latest, update packaging photos, add 3D printed part files
    [Bottom.brd, Bottom.sch, PinheaderCap1x8.step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]
2020-07-15 Move Arduino software in folder to make the IDE happy

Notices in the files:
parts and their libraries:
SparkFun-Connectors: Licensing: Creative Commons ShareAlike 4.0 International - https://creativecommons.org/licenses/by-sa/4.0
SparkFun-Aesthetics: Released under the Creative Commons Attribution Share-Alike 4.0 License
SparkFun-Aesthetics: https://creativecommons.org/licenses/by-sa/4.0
